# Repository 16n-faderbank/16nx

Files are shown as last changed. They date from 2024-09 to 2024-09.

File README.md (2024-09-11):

# 16nx: ECAD files

Electronics CAD and design for the 16nx faderbank, in KiCAD 8.0.4 format.

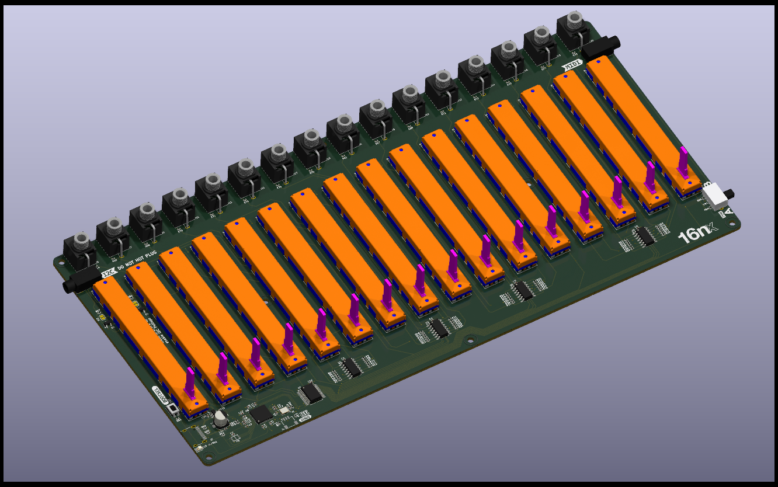
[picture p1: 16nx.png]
16nx board render


## Revision

Board revision C

## Design Notes

16nx is a redesign of the original [16n][16n] project. It has identical functionality to the original project. The changes are:

- replace Teensy 3.2 board with RP2040 microcontroller and supporting circuitry, directly on the board
- move to USB-C connector
- add more power filtering onto 5V line
- redesign analog circuitry for CV outs. Rather than running the faders at 5V and dividing down to ~3.2V for the microcontroller, 16nx runs at 3.3V everywhere, and amplifies fader values _up_ to ~5V via the MCP6004 opamps.
- move to vertical Thonkiconn jacks for CV outputs (cheaper, easier to access, easier to purchase)
- move to new horizontal jack parts for MIDI/I2C, ensuring there are no connectors on front panel (4332.2330 Schurter jacks)
- assume all SMT will be machine-placed; passives are now down to 0402, various QFN/USON parts that should be reflowed.

The only manual assembly anticipated on the board is of the through-hole components: faders, jacks, switch. Everything else is expected to be assembled via a PCBA house. The product is designed around relatively generic, off-the-shelf parts available at eg [JLC][jlc].

Gerbers are not committed to the repository; they will be supplied as part of releases.

## BOM

Bom is in `16nx-bom.csv`. It contains descriptions of parts and part numbers either at JLC or at Mouser, which is how the author built his boards. Thonkiconn are available from [Thonk][thonk].

In general, most of the passives requirements are not fussy: 1% resistors and capacitors with suitable voltage tolerance will be fine. The crystal and its capacitors are quite specifically chosen, as is the Winbond flash RAM.

The Alps faders are available in a number of resistances; the actual resistance of the fader doesn't matter, it's just being used as a voltage divider; if you can't get 10k but _can_ get 20k faders, that's fine. They **must** be linear taper, however. Do not use log/audio taper faders; you _cannot_ fix that in software. (Yes, people have asked.)

## Debug connector

The debug connector on the front of the board is a JST-SH connector breaking out ARM SWD (single-wire-debug) ready for connection to a [Pico Debug Probe][debugprobe]. This allows developers to use open-source debug tools (OpenOCD, [Cortex Debug](https://github.com/Marus/cortex-debug)) to debug the firmware in a more... pleasant manner than endless serial dumps.

## I2C pullups

Two 4.7kohm pullups are available for the I2C lines. To engage them, join the two solder jumpers at the top left of the board with a blob of solder. (You may not need these if you already have suitable pull-up impedance on your I2C lines).

## Pinouts

| GPIO | Description |
| ---- | --- |
| 2 | On board LED |
| 4 | UART TX (MIDI OUT) |
| 10 | SDA (I2C1) |
| 11 | SCL (I2C1) |
| 18 | S0 |
| 19 | S1 |
| 20 | S2 |
| 21 | S3 |
| 26 | ADC0 |

## Front panels

Alongside the usual KiCAD files, this directory also includes a `panels` directory containing DXF files for top/bottom panels, and a mechanical drawing of the top panel. A schematic in PDF format is also included.

## Licensing

As per the `LICENSE.md` file, the 16nx hardware is licensed as **[Creative Commons Attribution-Share-Alike 4.0][ccsa]**.

---

[octobom]: https://octopart.com/bom-tool/unJxkzvR
[16n]: https://github.com/16n-faderbank/16n/tree/main/electronics
[jlc]: https://jlcpcb.com/
[ccsa]: https://creativecommons.org/licenses/by-sa/4.0/legalcode
[thonk]: https://thonk.co.uk/

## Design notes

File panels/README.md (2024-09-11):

# 16nx panels

DXF files are included for top/bottom panels.

There's also a mechanical drawing for the top panel.

The bottom panel is identical top the top, minus the fader slots, jack holes,
and optional BOOTSEL pinhole.

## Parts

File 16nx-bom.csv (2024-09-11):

Reference | Value | Footprint | Qty | DNP | Description | JLCPCB Part | Mouser Part
C1,C2,C3,C4,C7,C8,C9,C10,C11,C12,C13,C14,C15,C16,C19,C20 | 100n | 0402 | 16 |  | 100nF 16V X7R 10% capacitor | C1525
C5,C6 | 27p | 0402 | 2 |  | 27pF 50V C0G 5% capacitor | C1557
C17,C18,C22,C23 | 1u | 0402 | 4 |  | 1uF 25V X7R 10% capacitor | C52923
C21 | 47u | 5x5.4mm capacitor | 1 |  | 47uF 16V electrolytic capacitor | C4747957
D1,D2 | BAT54S | SOT-23 | 2 |  | series schottky diode | C916425
D3 | LED_Small | 0805 | 1 |  | Red LED | C84256
J1,J2 | AudioJack3_SwitchT | ta_library:Schurter 4832.2330 | 2 |  | Schurter 4832.2330 Jack Socket |  | 693-4832.233
J3 | USB_C_Receptacle_USB2.0 | Connector_USB:USB_C_Receptacle_HRO_TYPE-C-31-M-12 | 1 |  | Korean Hroparts C-13-M-12 USB-C socket | C165948
J4 | Conn_01x03 | ta_library:JST_SM03B-SRSS-TB(LF)(SN) | 1 |  | JST SM03B-SRSS-TB(LF)(SN) | C160403
J5,J6,J7,J8,J9,J10,J11,J12,J13,J14,J15,J16,J17,J18,J19,J20 | AudioJack2_SwitchT | ta_library:Thonkiconn | 16 |  | Thonkiconn Jack Connector
R1,R4,R7,R10,R13,R16,R19,R22,R25,R28,R31,R34,R37,R40,R43,R46,R51,R53,R61,R64,R65,R66,R67,R68,R69,R70,R71,R72,R73,R74,R75,R76,R77,R78,R79 | 1k | 0402 | 35 |  | 1kΩ 1% resistor | C11702
R2,R5,R8,R11,R14,R17,R20,R23,R26,R29,R32,R35,R38,R41,R44,R47 | 10k | 0402 | 16 |  | 10kΩ 1% resistor | C25744
R3,R6,R9,R12,R15,R18,R21,R24,R27,R30,R33,R36,R39,R42,R45,R48 | 5k6 | 0402 | 16 |  | 5.6kΩ 1% resistor | C25908
R49,R50 | 27.4 | 0402 | 2 |  | 27.4Ω 1% resistor | C284479
R52 | DNP | 0402 | 1
R54,R55 | 47 | 0402 | 2 |  | 47Ω 1% resistor | C25118
R56,R57 | 4k7 | 0402 | 2 |  | 4k7 1% resistor | C25900
R58,R59 | 5k1 | 0402 | 2 |  | 5.1kΩ 1% resistor | C25905
R62,R63 | 100 | 0402 | 2 |  | 100Ω 1% resistor | C25076
RV1,RV2,RV3,RV4,RV5,RV6,RV7,RV8,RV9,RV10,RV11,RV12,RV13,RV14,RV15,RV16 | R_Potentiometer | ta_library:Alps_60mm_Fader | 16 |  | Alps RS6011SP6003 fader |  | 688-RS6011SP6003
SW1 | SW_DPDT_x2 | ta_library:SW_E-Switch_EG2211_DPDT | 1 |  | EG2211 toggle switch |  | 612-EG2211
SW3 | SW_Push | Button_Switch_SMD:SW_SPST_EVQP2 | 1 |  | Panasonic EVQP2 3.5x4.7m SPST push switch | C79162
U1,U2,U3,U4 | MCP6004 | SOIC-14_3.9x8.7mm_P1.27mm | 4 |  | MCP6004 opamp | C7378
U5 | RP2040 | QFN56 | 1 |  | RP2040 microcontroller | C2040
U6 | W25Q16JVUXIQ | easyeda2kicad:USON-8_L3.0-W2.0-P0.50-BL-EP | 1 |  | Winbond W25Q16JVUXIQ flash memory | C2843335
U7 | CD74HC4067M | SSOP-24_5.3x8.2mm_P0.65mm | 1 |  | CD74HC4067 multiplexer | C98457
U8 | AP2112K-3.3 | SOT-23-5 | 1 |  | 3.3V LDO regulator | C3021085
Y1 | X322512MSB4SI | 3225-4Pin_3.2x2.5mm | 1 |  | 12MHz SMD crystal oscillator 20pf | C9002

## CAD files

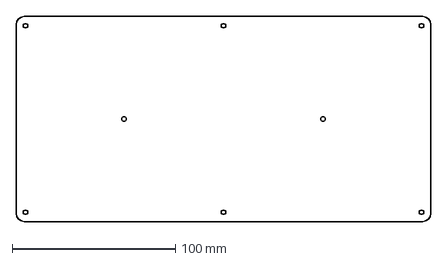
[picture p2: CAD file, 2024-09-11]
panels/16nx-bottom-panel.dxf
254.0 x 125.7 mm

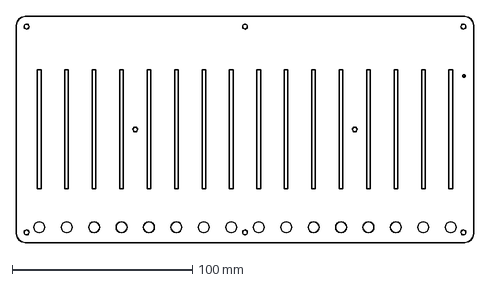
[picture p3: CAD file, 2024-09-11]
panels/16nx-top-panel.dxf
254.0 x 125.7 mm

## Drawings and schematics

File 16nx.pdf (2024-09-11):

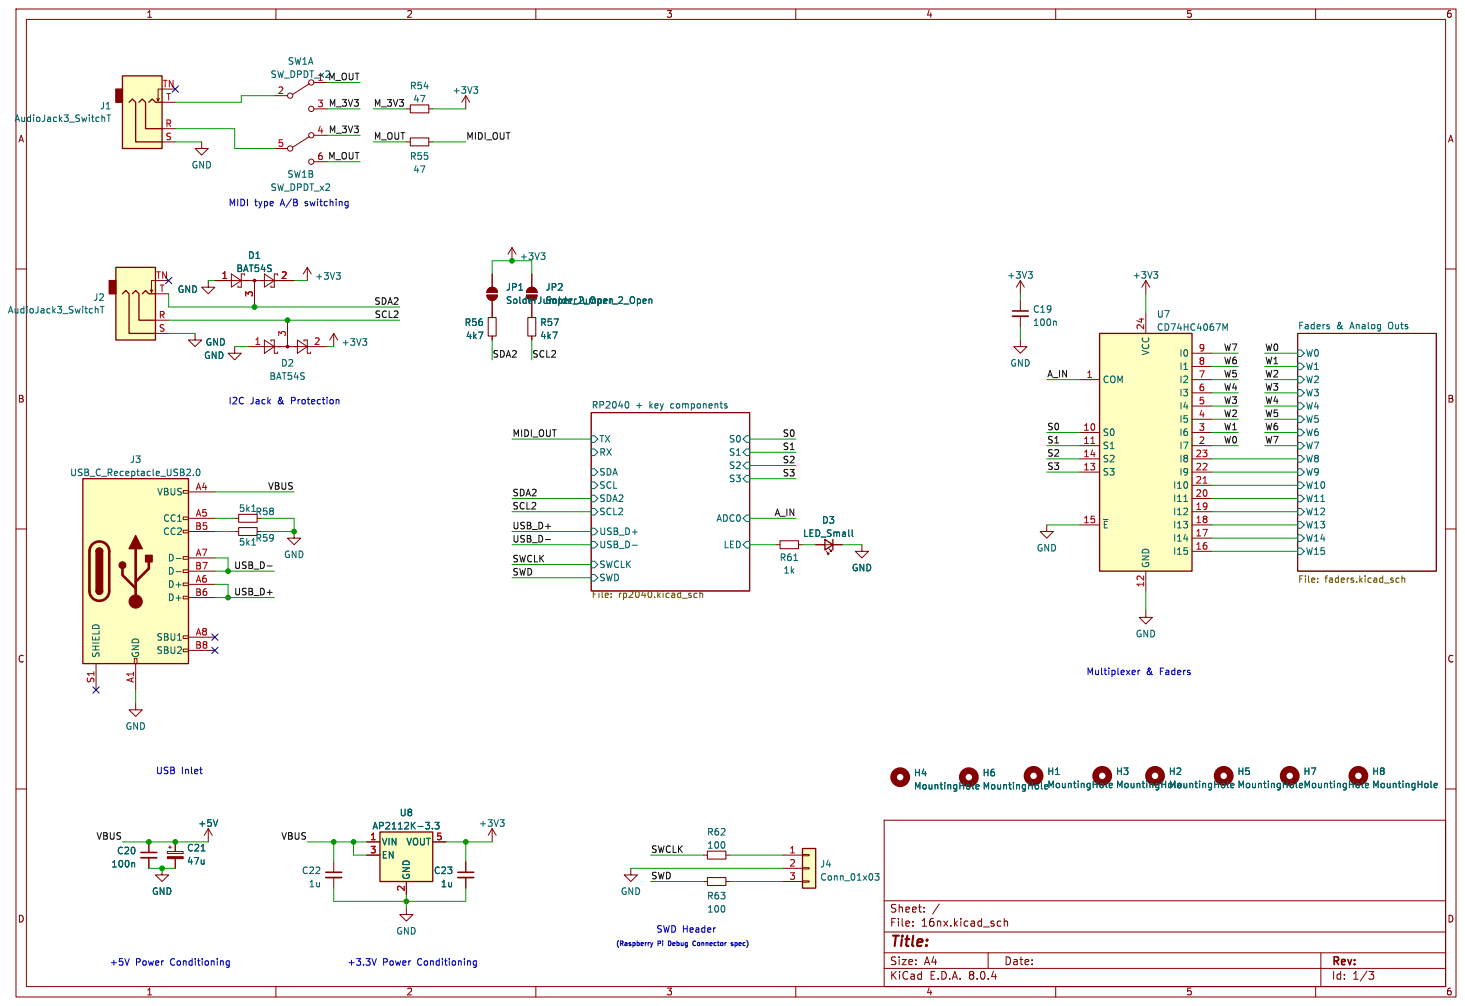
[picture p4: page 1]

I2C Jack & Protection MIDI type A/B switching GND

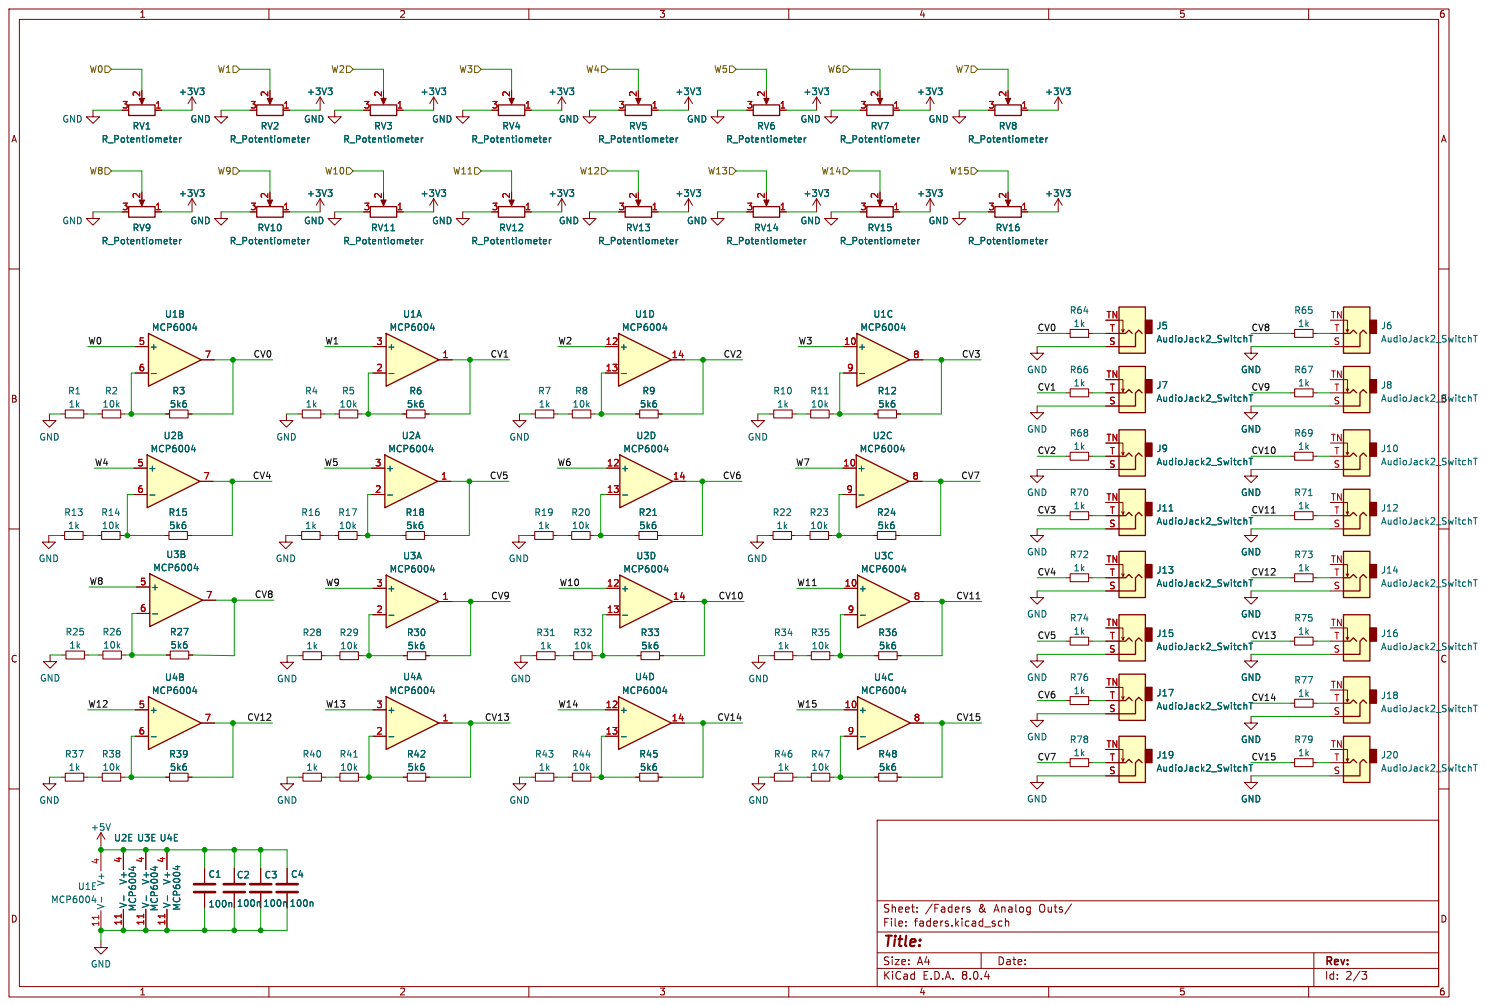
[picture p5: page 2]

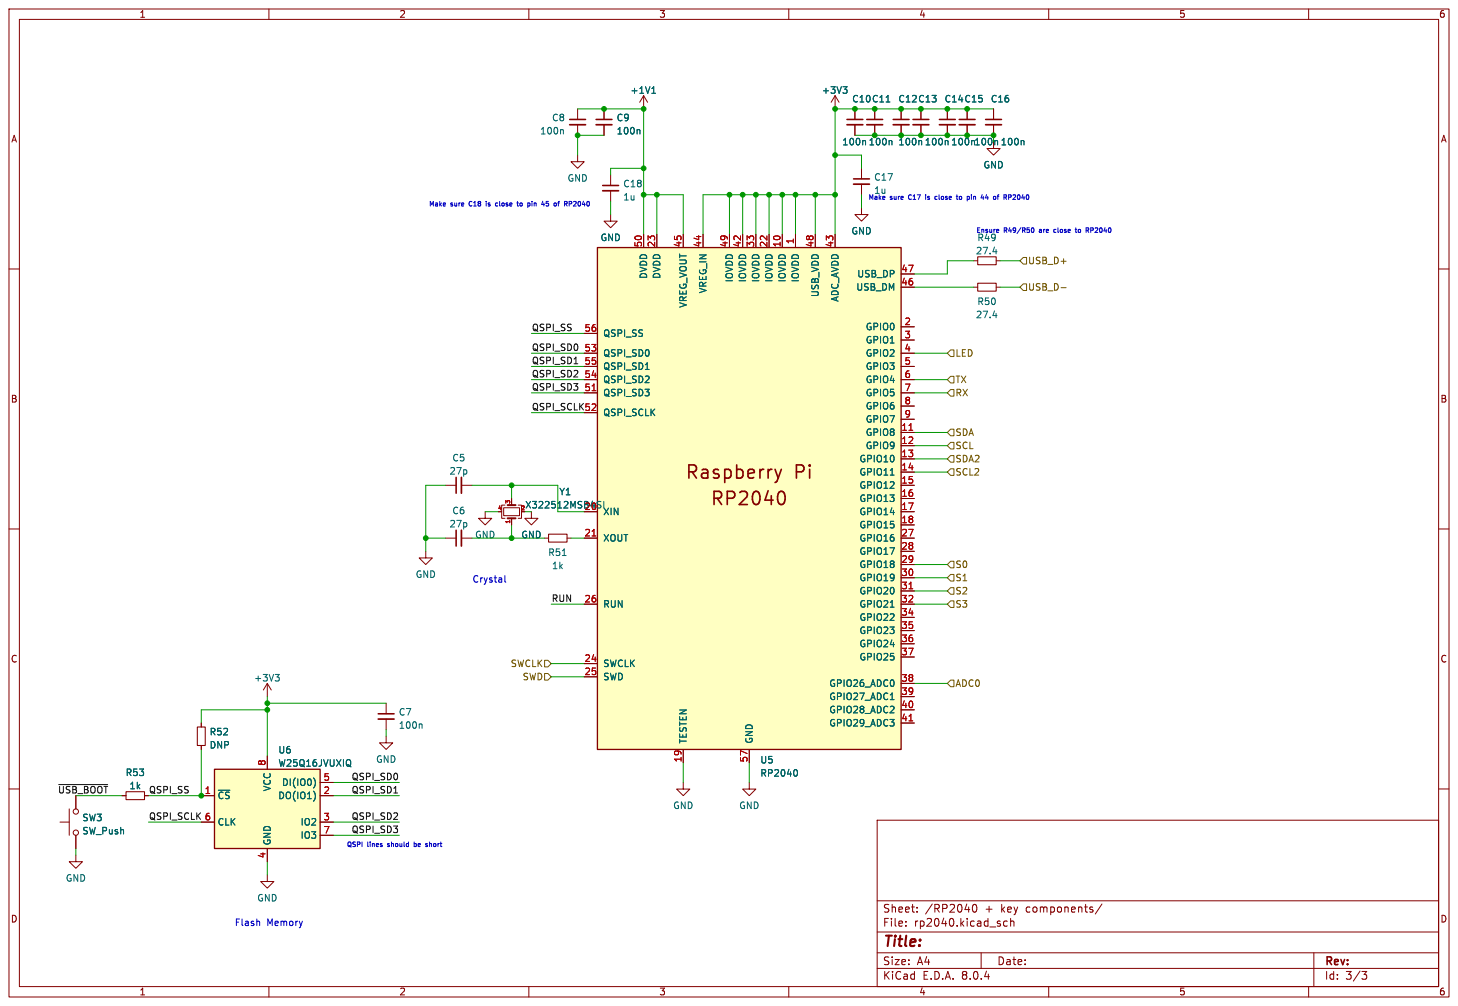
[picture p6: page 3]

Make sure C17 is close to pin 44 of RP2040

Make sure C18 is close to pin 45 of RP2040

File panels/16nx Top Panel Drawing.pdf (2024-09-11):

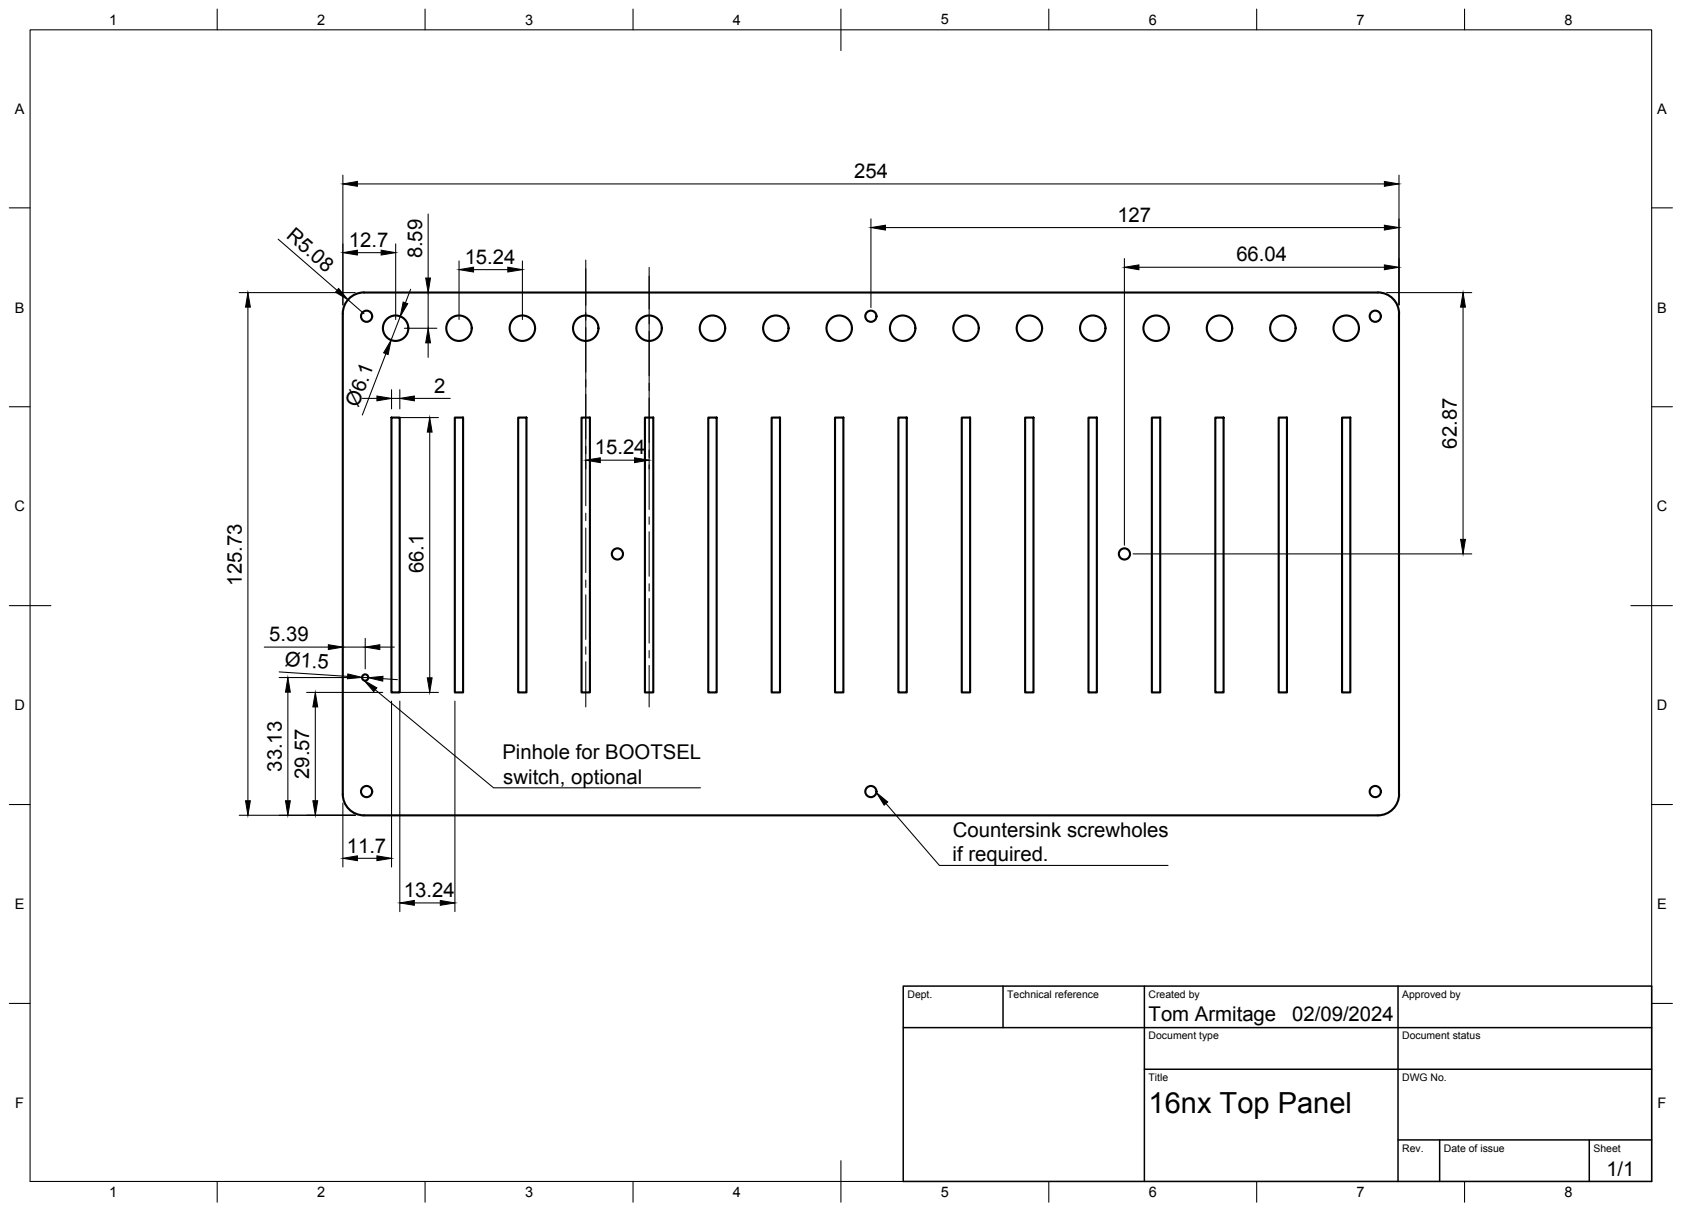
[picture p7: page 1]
Title; DWG No.; Rev.; Date of issue; Sheet; 16nx Top Panel; Countersink screwholes if required.

Pinhole for BOOTSEL
switch, optional

Dept. | Technical reference | Created by Tom Armitage 02/09/2024 | Approved by

Document type | Document status

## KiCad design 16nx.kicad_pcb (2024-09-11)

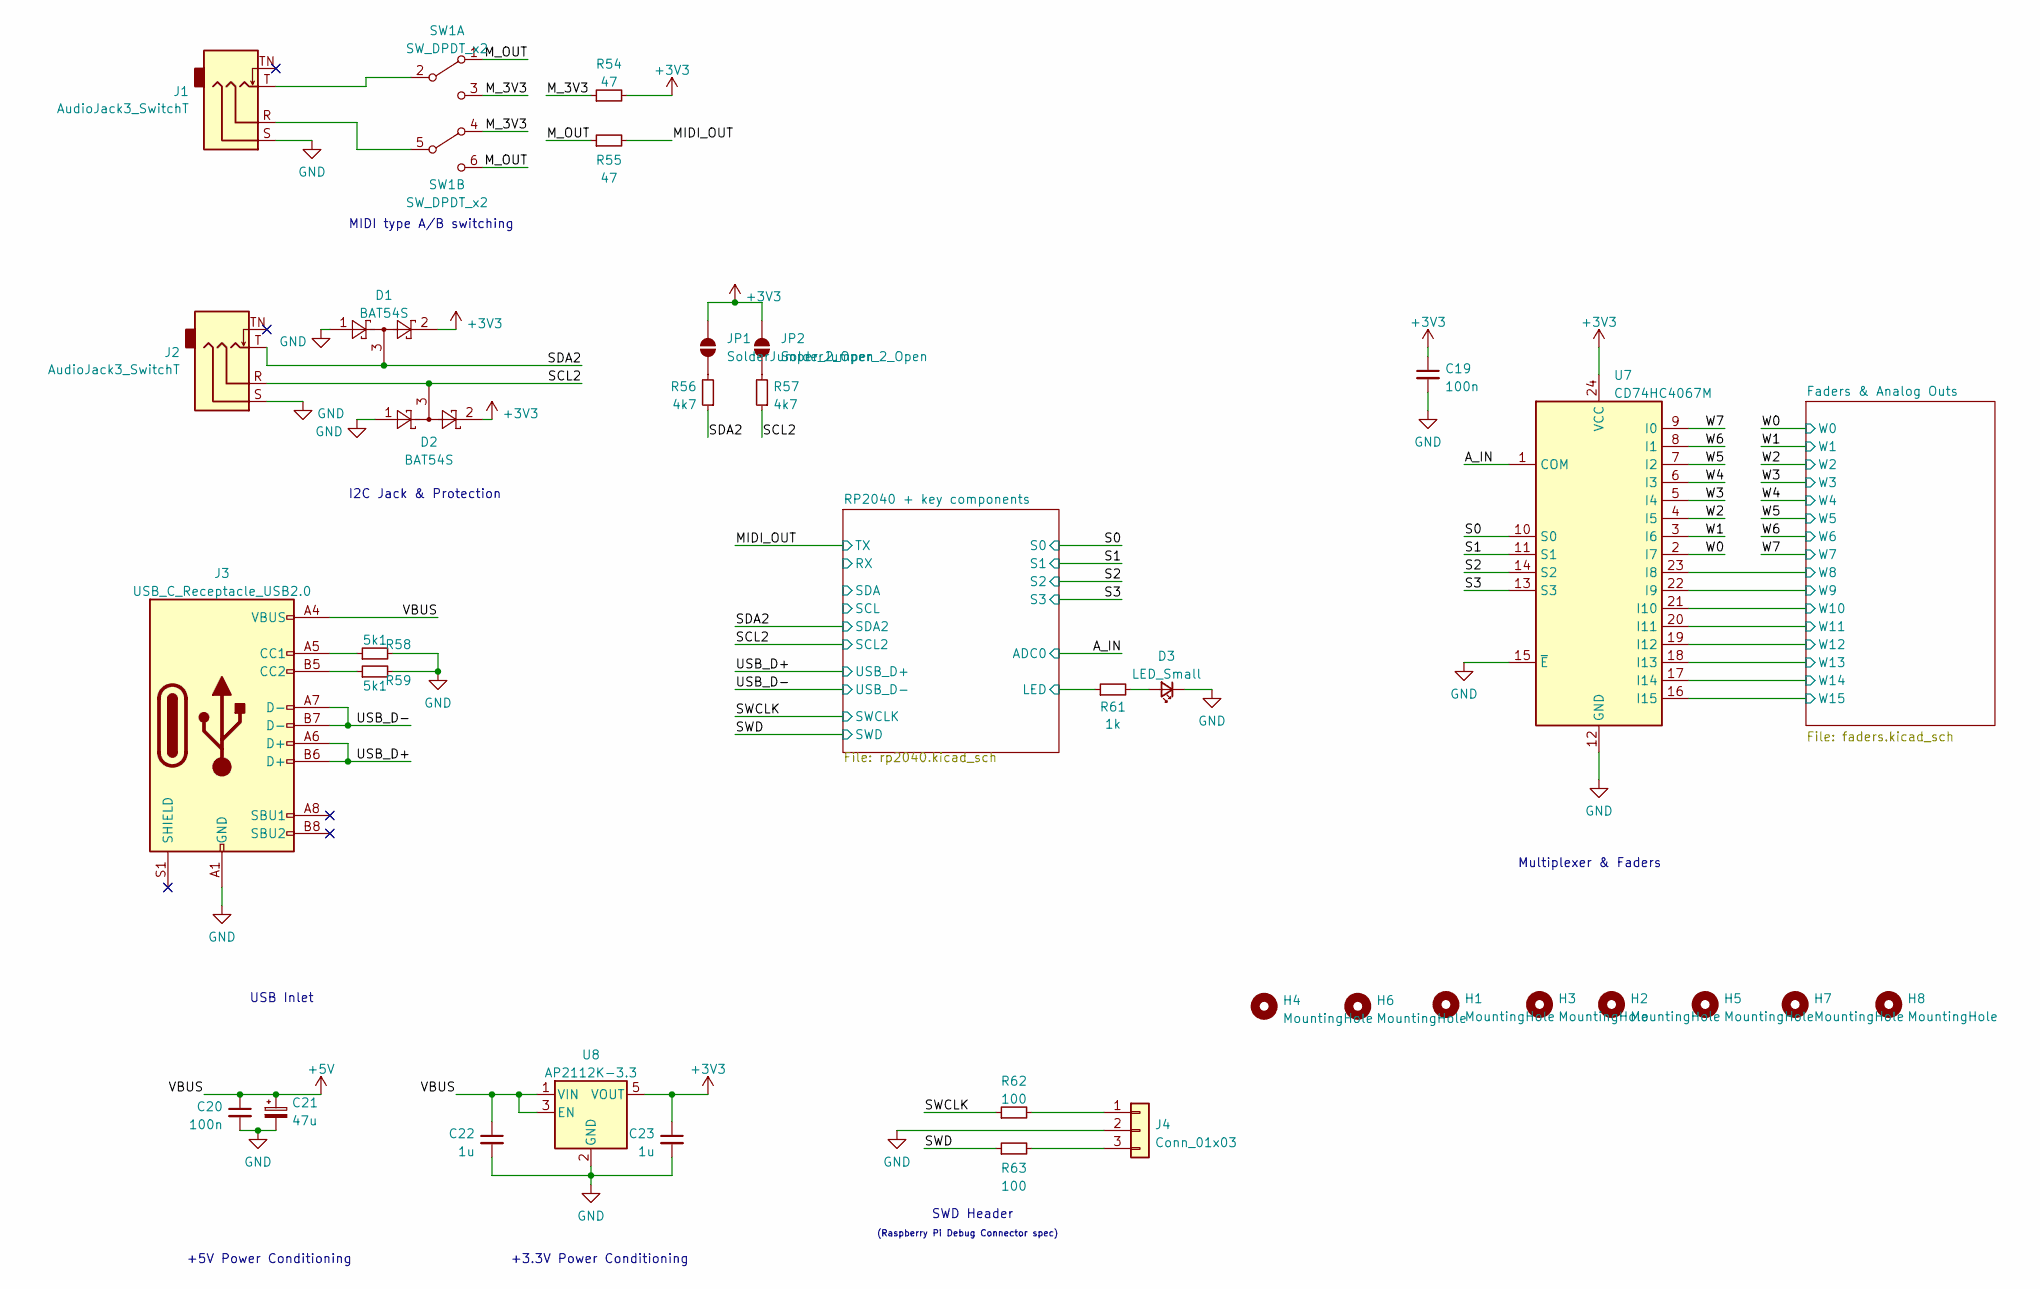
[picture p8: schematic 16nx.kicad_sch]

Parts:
C19, C20: 100n; C_0402_1005Metric
C21: 47u; CP_Elec_5x5.4
C22, C23: 1u; C_0402_1005Metric
D1, D2: BAT54S; SOT-23
D3: LED_Small; LED_0805_2012Metric_Pad1.15x1.40mm_HandSolder
H1, H2, H3, H4, H5, H6, H7, H8: MountingHole; MountingHole_2.7mm_M2.5
J1, J2: AudioJack3_SwitchT; Schurter 4832.2330
J3: USB_C_Receptacle_USB2.0; USB_C_Receptacle_HRO_TYPE-C-31-M-12
J4: Conn_01x03; JST_SM03B-SRSS-TB(LF)(SN)
JP1, JP2: SolderJumper_2_Open; SolderJumper-2_P1.3mm_Open_RoundedPad1.0x1.5mm
R54, R55: 47; R_0402_1005Metric
R56, R57: 4k7; R_0402_1005Metric
R58, R59: 5k1; R_0402_1005Metric
R61: 1k; R_0402_1005Metric
R62, R63: 100; R_0402_1005Metric
SW1: SW_DPDT_x2; SW_E-Switch_EG2211_DPDT
U7: CD74HC4067M; SSOP-24_5.3x8.2mm_P0.65mm
U8: AP2112K-3.3; SOT-23-5

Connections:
+3V3: C19.1, C23.1, D1.2, D2.2, JP1.2 (B), JP2.2 (B), R54.2, U7.24 (VCC), U8.5 (VOUT); also elsewhere on the board
+5V: C20.1, C21.1, C22.1, J3.A4 (VBUS), J3.A9 (VBUS), J3.B4 (VBUS), J3.B9 (VBUS), U8.1 (VIN), U8.3 (EN); also elsewhere on the board
/A_IN: U7.1 (COM); also elsewhere on the board
/Faders & Analog Outs/W8: U7.23 (I8); also elsewhere on the board
/Faders & Analog Outs/W9: U7.22 (I9); also elsewhere on the board
/Faders & Analog Outs/W10: U7.21 (I10); also elsewhere on the board
/Faders & Analog Outs/W11: U7.20 (I11); also elsewhere on the board
/Faders & Analog Outs/W12: U7.19 (I12); also elsewhere on the board
/Faders & Analog Outs/W13: U7.18 (I13); also elsewhere on the board
/Faders & Analog Outs/W14: U7.17 (I14); also elsewhere on the board
/Faders & Analog Outs/W15: U7.16 (I15); also elsewhere on the board
/MIDI_OUT: R55.2; also elsewhere on the board
/M_3V3: R54.1, SW1.3 (C), SW1.4 (A)
/M_OUT: R55.1, SW1.1 (A), SW1.6 (C)
/RP2040 + key components/LED: R61.1; also elsewhere on the board
/S0: U7.10 (S0); also elsewhere on the board
/S1: U7.11 (S1); also elsewhere on the board
/S2: U7.14 (S2); also elsewhere on the board
/S3: U7.13 (S3); also elsewhere on the board
/SCL2: D2.3, J2.R, R57.1; also elsewhere on the board
/SDA2: D1.3, J2.T, R56.1; also elsewhere on the board
/SWCLK: R62.1; also elsewhere on the board
/SWD: R63.1; also elsewhere on the board
/USB_D+: J3.A6 (D+), J3.B6 (D+); also elsewhere on the board
/USB_D-: J3.A7 (D-), J3.B7 (D-); also elsewhere on the board
/W0: U7.2 (I7); also elsewhere on the board
/W1: U7.3 (I6); also elsewhere on the board
/W2: U7.4 (I5); also elsewhere on the board
/W3: U7.5 (I4); also elsewhere on the board
/W4: U7.6 (I3); also elsewhere on the board
/W5: U7.7 (I2); also elsewhere on the board
/W6: U7.8 (I1); also elsewhere on the board
/W7: U7.9 (I0); also elsewhere on the board
GND: C19.2, C20.2, C21.2, C22.2, C23.2, D1.1, D2.1, D3.1 (K), J1.S, J2.S, J3.A1 (GND), J3.A12 (GND), J3.B1 (GND), J3.B12 (GND), J4.2, R58.2, R59.2, U7.12 (GND), U7.15 (~E), U8.2 (GND); also elsewhere on the board
unnamed: D3.2 (A), R61.2
unnamed: J3.A5 (CC1), R58.1
unnamed: J3.B5 (CC2), R59.1
unnamed: J4.1, R62.2
unnamed: J4.3, R63.2
unnamed: JP1.1 (A), R56.2
unnamed: JP2.1 (A), R57.2
unnamed: J1.T, SW1.2 (B)
unnamed: J1.R, SW1.5 (B)

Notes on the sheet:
USB Inlet
+5V Power Conditioning
I2C Jack & Protection
SWD Header
+3.3V Power Conditioning
MIDI type A/B switching
(Raspberry Pi Debug Connector spec)
Multiplexer & Faders

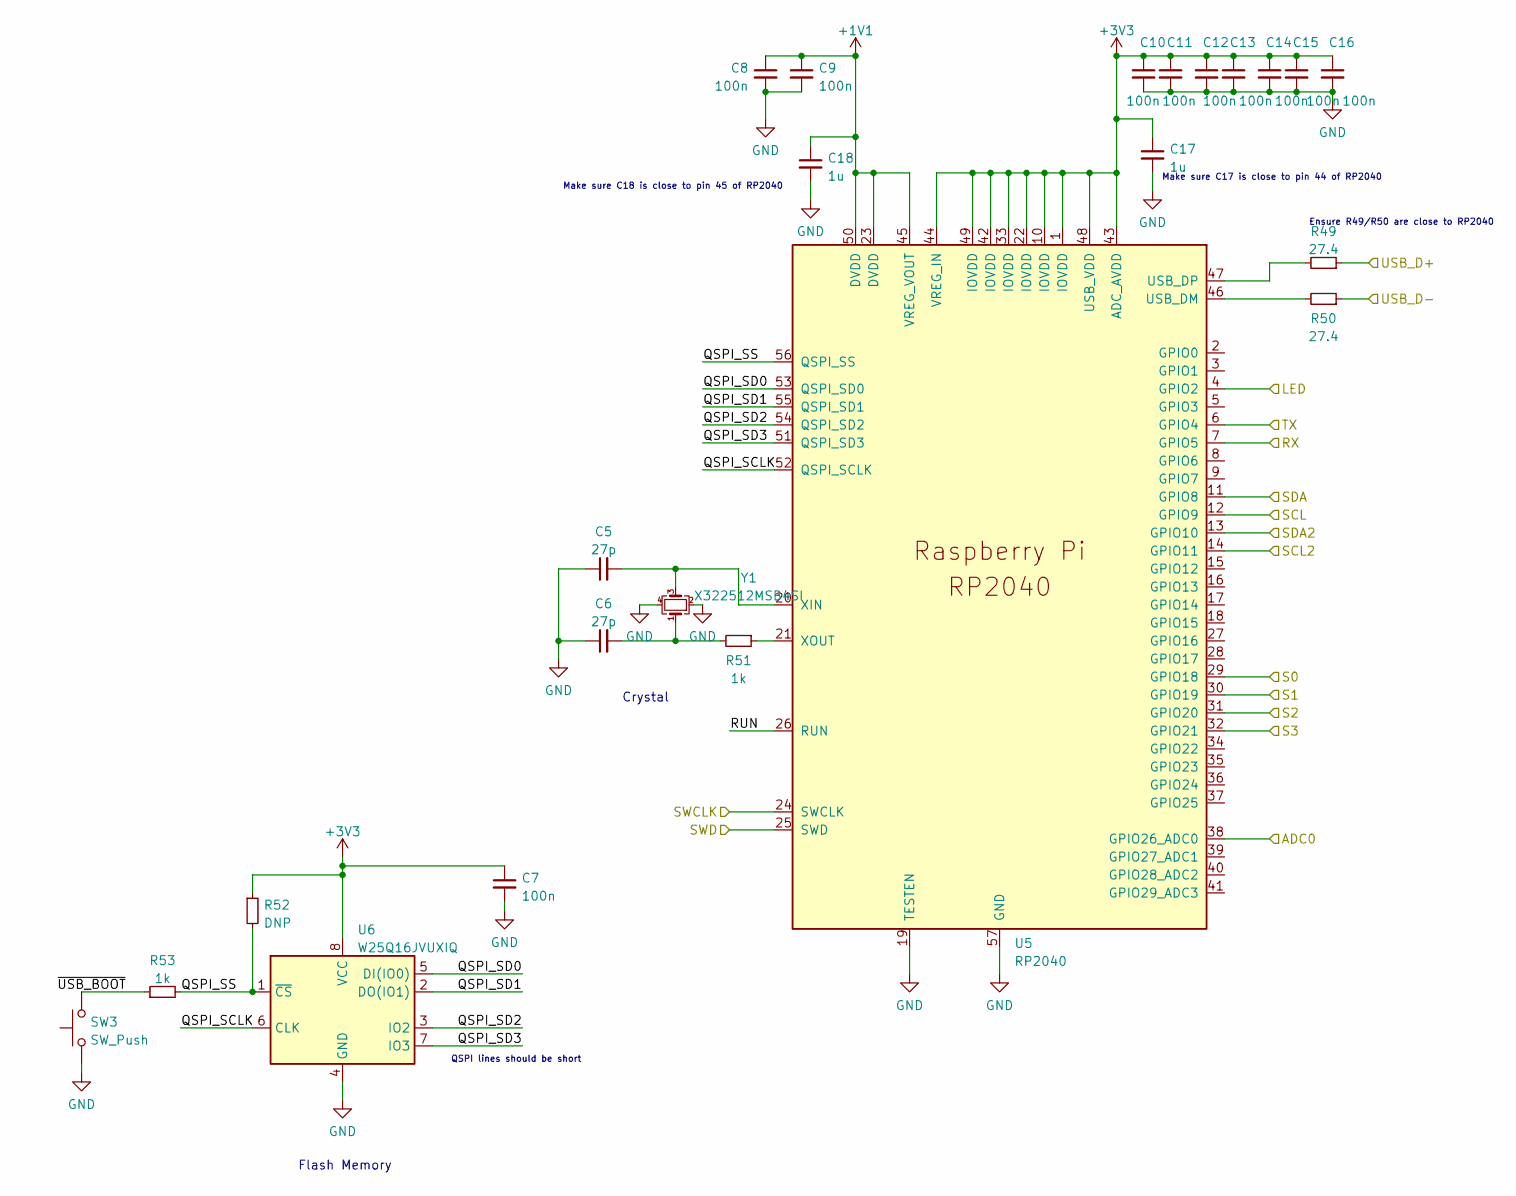
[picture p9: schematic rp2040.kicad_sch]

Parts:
C5, C6: 27p; C_0402_1005Metric
C7, C8, C9, C10, C11, C12, C13, C14, C15, C16: 100n; C_0402_1005Metric
C17, C18: 1u; C_0402_1005Metric
R49, R50: 27.4; R_0402_1005Metric
R51, R53: 1k; R_0402_1005Metric
R52: DNP; R_0402_1005Metric
SW3: SW_Push; SW_SPST_EVQP2
U5: RP2040; RP2040-QFN-56
U6: W25Q16JVUXIQ; USON-8_L3.0-W2.0-P0.50-BL-EP
Y1: X322512MSB4SI; Crystal_SMD_3225-4Pin_3.2x2.5mm

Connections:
+1V1: C8.1, C9.1, C18.1, U5.23 (DVDD), U5.45 (VREG_VOUT), U5.50 (DVDD)
+3V3: C7.1, C10.1, C11.1, C12.1, C13.1, C14.1, C15.1, C16.1, C17.1, R52.1, U5.1 (IOVDD), U5.10 (IOVDD), U5.22 (IOVDD), U5.33 (IOVDD), U5.42 (IOVDD), U5.43 (ADC_AVDD), U5.44 (VREG_IN), U5.48 (USB_VDD), U5.49 (IOVDD), U6.8 (VCC); also elsewhere on the board
/A_IN: U5.38 (GPIO26_ADC0); also elsewhere on the board
/MIDI_OUT: U5.6 (GPIO4); also elsewhere on the board
/RP2040 + key components/LED: U5.4 (GPIO2); also elsewhere on the board
/RP2040 + key components/QSPI_SCLK: U5.52 (QSPI_SCLK), U6.6 (CLK)
/RP2040 + key components/QSPI_SD0: U5.53 (QSPI_SD0), U6.5 (DI(IO0))
/RP2040 + key components/QSPI_SD1: U5.55 (QSPI_SD1), U6.2 (DO(IO1))
/RP2040 + key components/QSPI_SD2: U5.54 (QSPI_SD2), U6.3 (IO2)
/RP2040 + key components/QSPI_SD3: U5.51 (QSPI_SD3), U6.7 (IO3)
/RP2040 + key components/QSPI_SS: R52.2, R53.2, U5.56 (QSPI_SS), U6.1 (~CS)
/RP2040 + key components/RUN: U5.26 (RUN)
/RP2040 + key components/RX: U5.7 (GPIO5)
/RP2040 + key components/SCL: U5.12 (GPIO9)
/RP2040 + key components/SDA: U5.11 (GPIO8)
/RP2040 + key components/~USB_BOOT: R53.1, SW3.2
/S0: U5.29 (GPIO18); also elsewhere on the board
/S1: U5.30 (GPIO19); also elsewhere on the board
/S2: U5.31 (GPIO20); also elsewhere on the board
/S3: U5.32 (GPIO21); also elsewhere on the board
/SCL2: U5.14 (GPIO11); also elsewhere on the board
/SDA2: U5.13 (GPIO10); also elsewhere on the board
/SWCLK: U5.24 (SWCLK); also elsewhere on the board
/SWD: U5.25 (SWD); also elsewhere on the board
/USB_D+: R49.1; also elsewhere on the board
/USB_D-: R50.1; also elsewhere on the board
GND: C5.1, C6.1, C7.2, C8.2, C9.2, C10.2, C11.2, C12.2, C13.2, C14.2, C15.2, C16.2, C17.2, C18.2, SW3.1, U5.19 (TESTEN), U5.57 (GND), U6.4 (GND), Y1.2, Y1.4; also elsewhere on the board
unnamed: C6.2, R51.2, Y1.1
unnamed: R50.2, U5.46 (USB_DM)
unnamed: R49.2, U5.47 (USB_DP)
unnamed: C5.2, U5.20 (XIN), Y1.3
unnamed: R51.1, U5.21 (XOUT)

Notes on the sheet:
Crystal
Ensure R49/R50 are close to RP2040
Make sure C17 is close to pin 44 of RP2040
Flash Memory
QSPI lines should be short
Make sure C18 is close to pin 45 of RP2040

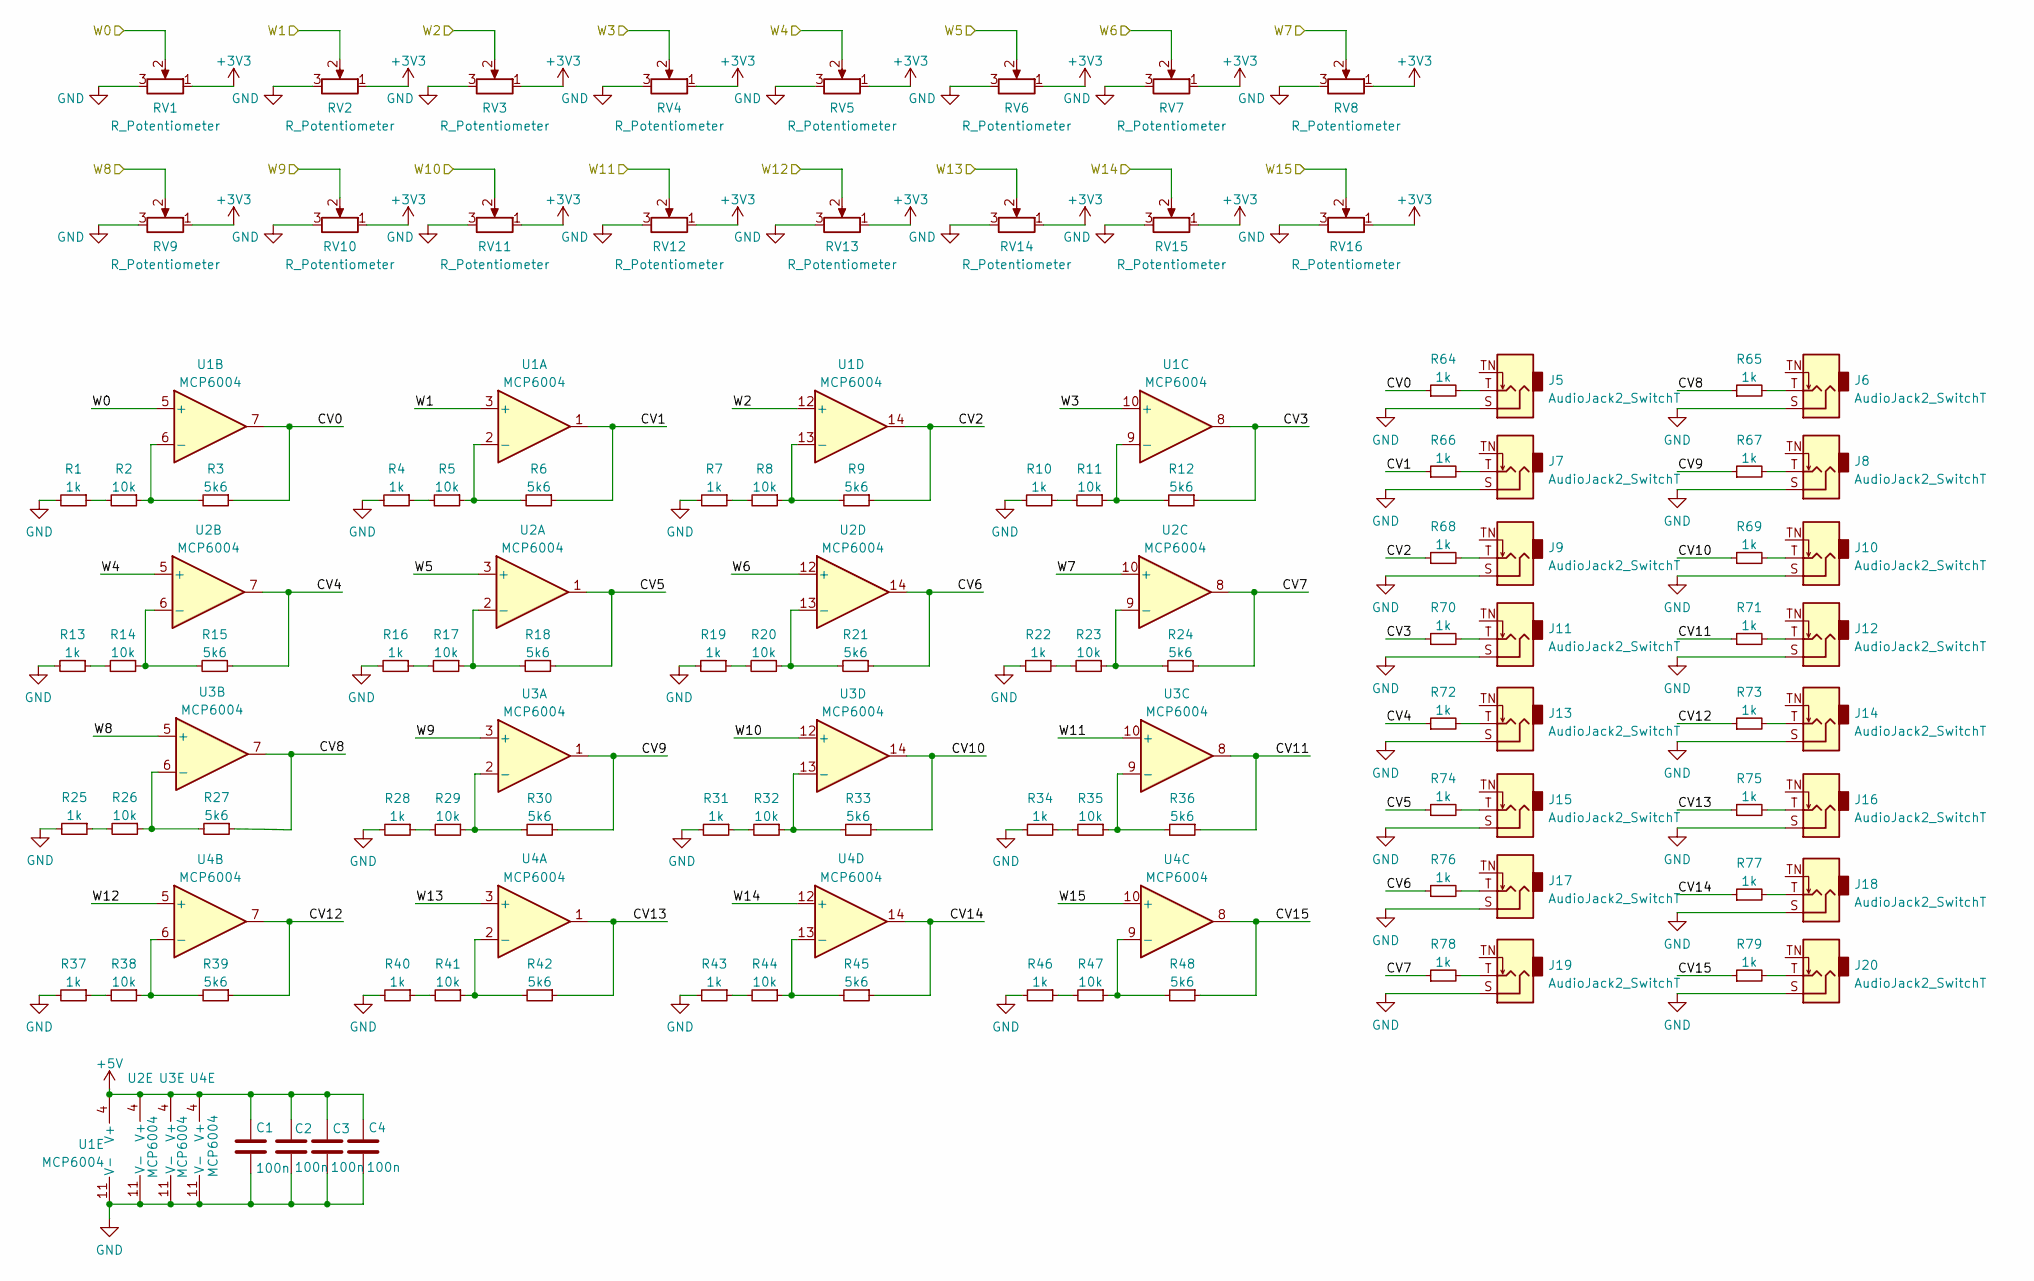
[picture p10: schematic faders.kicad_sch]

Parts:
C1, C2, C3, C4: 100n; C_0402_1005Metric
J5, J6, J7, J8, J9, J10, J11, J12, J13, J14, J15, J16, J17, J18, J19, J20: AudioJack2_SwitchT; Thonkiconn
R1, R4, R7, R10, R13, R16, R19, R22, R25, R28, R31, R34, R37, R40, R43, R46, R64, R65, R66, R67, R68, R69, R70, R71, R72, R73, R74, R75, R76, R77, R78, R79: 1k; R_0402_1005Metric
R2, R5, R8, R11, R14, R17, R20, R23, R26, R29, R32, R35, R38, R41, R44, R47: 10k; R_0402_1005Metric
R3, R6, R9, R12, R15, R18, R21, R24, R27, R30, R33, R36, R39, R42, R45, R48: 5k6; R_0402_1005Metric
RV1, RV2, RV3, RV4, RV5, RV6, RV7, RV8, RV9, RV10, RV11, RV12, RV13, RV14, RV15, RV16: R_Potentiometer; Alps_60mm_Fader
U1, U2, U3, U4: MCP6004; SOIC-14_3.9x8.7mm_P1.27mm

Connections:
+3V3: RV1.1, RV2.1, RV3.1, RV4.1, RV5.1, RV6.1, RV7.1, RV8.1, RV9.1, RV10.1, RV11.1, RV12.1, RV13.1, RV14.1, RV15.1, RV16.1; also elsewhere on the board
+5V: C1.1, C2.1, C3.1, C4.1, U1.4 (V+), U2.4 (V+), U3.4 (V+), U4.4 (V+); also elsewhere on the board
/Faders & Analog Outs/CV0: R3.1, R64.1, U1.7
/Faders & Analog Outs/CV1: R6.1, R66.1, U1.1
/Faders & Analog Outs/CV2: R9.1, R68.1, U1.14
/Faders & Analog Outs/CV3: R12.1, R70.1, U1.8
/Faders & Analog Outs/CV4: R15.1, R72.1, U2.7
/Faders & Analog Outs/CV5: R18.1, R74.1, U2.1
/Faders & Analog Outs/CV6: R21.1, R76.1, U2.14
/Faders & Analog Outs/CV7: R24.1, R78.1, U2.8
/Faders & Analog Outs/CV8: R27.1, R65.1, U3.7
/Faders & Analog Outs/CV9: R30.1, R67.1, U3.1
/Faders & Analog Outs/CV10: R33.1, R69.1, U3.14
/Faders & Analog Outs/CV11: R36.1, R71.1, U3.8
/Faders & Analog Outs/CV12: R39.1, R73.1, U4.7
/Faders & Analog Outs/CV13: R42.1, R75.1, U4.1
/Faders & Analog Outs/CV14: R45.1, R77.1, U4.14
/Faders & Analog Outs/CV15: R48.1, R79.1, U4.8
/Faders & Analog Outs/W8: RV9.2, U3.5 (+); also elsewhere on the board
/Faders & Analog Outs/W9: RV10.2, U3.3 (+); also elsewhere on the board
/Faders & Analog Outs/W10: RV11.2, U3.12 (+); also elsewhere on the board
/Faders & Analog Outs/W11: RV12.2, U3.10 (+); also elsewhere on the board
/Faders & Analog Outs/W12: RV13.2, U4.5 (+); also elsewhere on the board
/Faders & Analog Outs/W13: RV14.2, U4.3 (+); also elsewhere on the board
/Faders & Analog Outs/W14: RV15.2, U4.12 (+); also elsewhere on the board
/Faders & Analog Outs/W15: RV16.2, U4.10 (+); also elsewhere on the board
/W0: RV1.2, U1.5 (+); also elsewhere on the board
/W1: RV2.2, U1.3 (+); also elsewhere on the board
/W2: RV3.2, U1.12 (+); also elsewhere on the board
/W3: RV4.2, U1.10 (+); also elsewhere on the board
/W4: RV5.2, U2.5 (+); also elsewhere on the board
/W5: RV6.2, U2.3 (+); also elsewhere on the board
/W6: RV7.2, U2.12 (+); also elsewhere on the board
/W7: RV8.2, U2.10 (+); also elsewhere on the board
GND: C1.2, C2.2, C3.2, C4.2, J5.S, J6.S, J7.S, J8.S, J9.S, J10.S, J11.S, J12.S, J13.S, J14.S, J15.S, J16.S, J17.S, J18.S, J19.S, J20.S, R1.2, R4.2, R7.2, R10.2, R13.2, R16.2, R19.2, R22.2, R25.2, R28.2, R31.2, R34.2, R37.2, R40.2, R43.2, R46.2, RV1.3, RV2.3, RV3.3, RV4.3, RV5.3, RV6.3, RV7.3, RV8.3, RV9.3, RV10.3, RV11.3, RV12.3, RV13.3, RV14.3, RV15.3, RV16.3, U1.11 (V-), U2.11 (V-), U3.11 (V-), U4.11 (V-); also elsewhere on the board
unnamed: J5.T, R64.2
unnamed: J6.T, R65.2
unnamed: J7.T, R66.2
unnamed: J8.T, R67.2
unnamed: J9.T, R68.2
unnamed: J10.T, R69.2
unnamed: J11.T, R70.2
unnamed: J12.T, R71.2
unnamed: J13.T, R72.2
unnamed: J14.T, R73.2
unnamed: J15.T, R74.2
unnamed: J16.T, R75.2
unnamed: J17.T, R76.2
unnamed: J18.T, R77.2
unnamed: J19.T, R78.2
unnamed: J20.T, R79.2
unnamed: R1.1, R2.2
unnamed: R4.1, R5.2
unnamed: R7.1, R8.2
unnamed: R10.1, R11.2
unnamed: R13.1, R14.2
unnamed: R16.1, R17.2
unnamed: R19.1, R20.2
unnamed: R22.1, R23.2
unnamed: R25.1, R26.2
unnamed: R28.1, R29.2
unnamed: R31.1, R32.2
unnamed: R34.1, R35.2
unnamed: R37.1, R38.2
unnamed: R40.1, R41.2
unnamed: R43.1, R44.2
unnamed: R46.1, R47.2
unnamed: R5.1, R6.2, U1.2 (-)
unnamed: R2.1, R3.2, U1.6 (-)
unnamed: R11.1, R12.2, U1.9 (-)
unnamed: R8.1, R9.2, U1.13 (-)
unnamed: R17.1, R18.2, U2.2 (-)
unnamed: R14.1, R15.2, U2.6 (-)
unnamed: R23.1, R24.2, U2.9 (-)
unnamed: R20.1, R21.2, U2.13 (-)
unnamed: R29.1, R30.2, U3.2 (-)
unnamed: R26.1, R27.2, U3.6 (-)
unnamed: R35.1, R36.2, U3.9 (-)
unnamed: R32.1, R33.2, U3.13 (-)
unnamed: R41.1, R42.2, U4.2 (-)
unnamed: R38.1, R39.2, U4.6 (-)
unnamed: R47.1, R48.2, U4.9 (-)
unnamed: R44.1, R45.2, U4.13 (-)

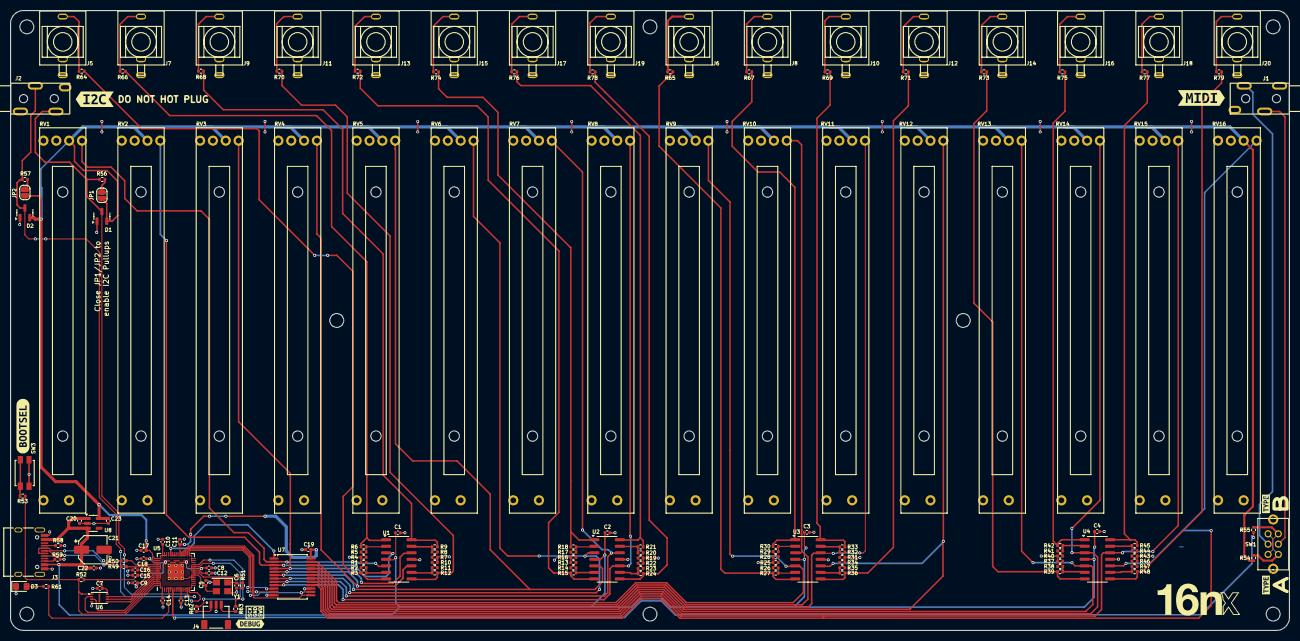
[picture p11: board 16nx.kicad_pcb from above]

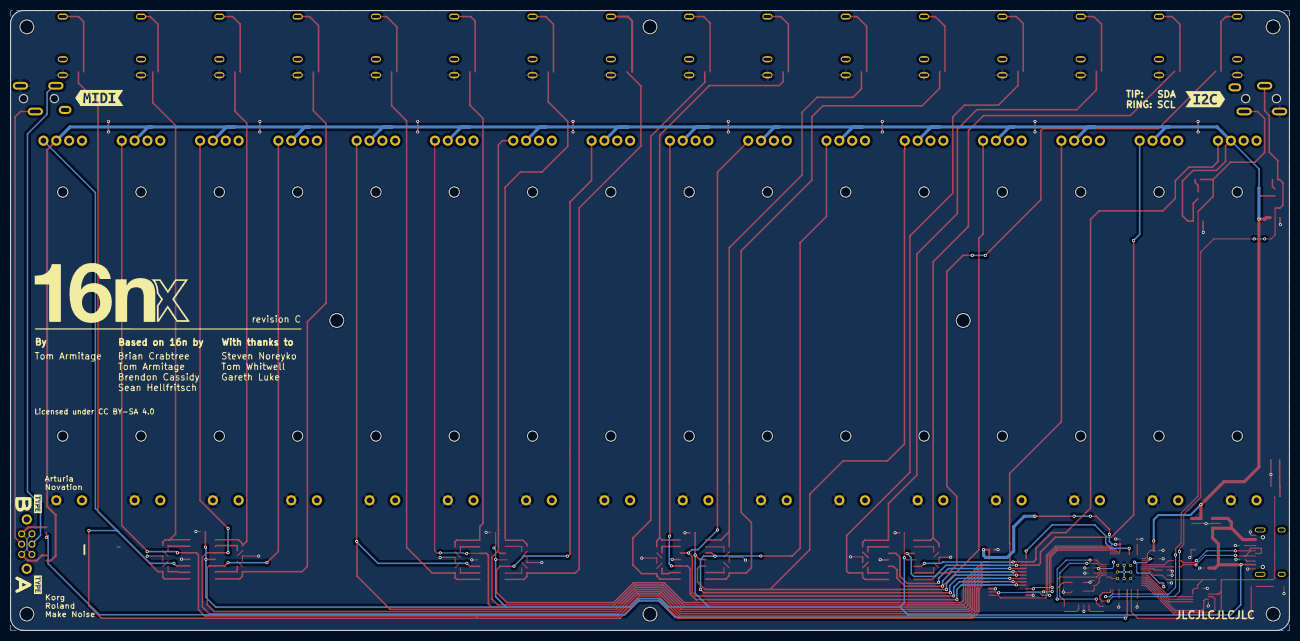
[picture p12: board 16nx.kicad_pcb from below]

Board: 2 copper layers, 248.9 x 120.7 mm, 171 parts (4 on the bottom side), 120 nets.

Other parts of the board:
kibuzzard-65F9938A, kibuzzard-65F9938A#2: G***; kibuzzard-65F9938A
kibuzzard-65F99372, kibuzzard-65F99372#2: G***; kibuzzard-65F99372
kibuzzard-65F99422: G***; kibuzzard-65F99422
kibuzzard-65F99486: G***; kibuzzard-65F99486
kibuzzard-66DB278F: G***; kibuzzard-66DB278F
kibuzzard-66DB2915: G***; kibuzzard-66DB2915
kibuzzard-6499C329: G***; kibuzzard-6499C329
kibuzzard-64709A08: G***; kibuzzard-64709A08

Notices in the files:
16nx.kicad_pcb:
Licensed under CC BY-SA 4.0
